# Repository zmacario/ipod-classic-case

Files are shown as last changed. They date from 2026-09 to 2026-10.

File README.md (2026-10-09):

# iPod Classic case — v2

A reworked three-piece screw-together case for the iPod Classic. The three
parts sandwich the iPod: a face plate with the screen and click-wheel
openings, a thick middle frame that holds the device, and a plain rear plate.

Everything is generated from [`generate_case.py`](generate_case.py), so the
design is parametric — edit the numbers at the top and run it again.

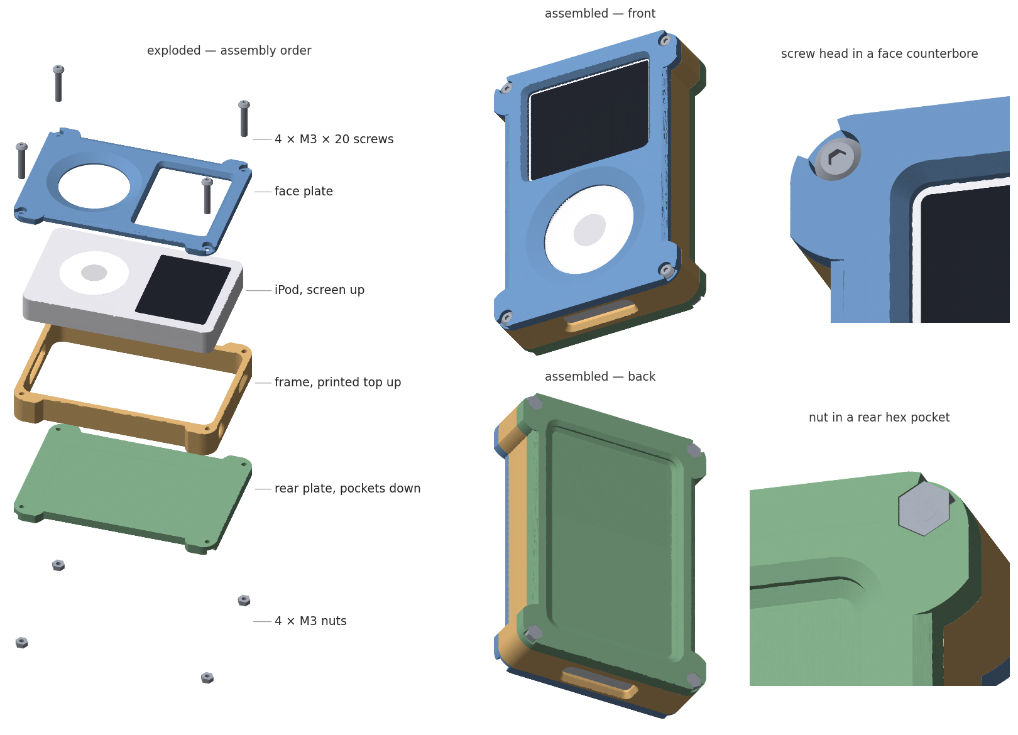
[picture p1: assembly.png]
Assembly of the three v2 parts: exploded order, both assembled sides, and a screw head and a nut in their corner pockets


## What changed from the original

| | original | v2 |
|---|---|---|
| rear plate | 3.50 mm | **5.00 mm** |
| screw length | nothing standard fitted | **M3 × 20, flush** |
| Hold switch | no opening | **14.0 × 5.0 mm window** |
| jack / dock / Hold openings | straight bores | **flared outwards** |
| bottom wall | 5.00 mm | **3.00 mm**, same as the top |
| outer size | 76.80 × 112.20 mm | **76.80 × 110.20 mm** |
| frame/face/rear side walls | solid, 7.30 mm all round | **thin waist, thick only at the screws** |
| face/rear edges | bevel all round, plus a finger-grip scallop on the lower half of each side | **frame's outline, with a bevel along each whole side between the corner pads** |

### Screw length

On the original the path from the counterbore floor to the outer face of the
rear plate measured **18.54 mm**, so an M3 × 20 stood 1.46 mm proud. M3 × 16
could never work: the frame alone is 14 mm, which leaves 2 mm to cross both
plates *and* engage the nut — less than the 2.40 mm thickness of the nut.

The fix was to thicken the rear plate, not the face plate. The rear is a plain
slab, so thickness costs nothing there; thickening the face would sink the
screen and click wheel to the bottom of deeper wells.

| | |
|---|---|
| material under the screw head | 1.000 mm |
| frame | 14.000 mm |
| rear web to the nut | 2.500 mm |
| nut pocket | 2.500 mm |
| **total** | **20.000 mm** |

An M3 × 20 now ends flush with the outer face, with 2.50 mm of thread engaged
in a 2.40 mm nut. Assembled height went from 21.00 to 22.50 mm.

This is what the tested build uses. An M3 × 18 would have allowed a thinner
rear plate, but it could not be found in shops, so the rear stays at 5.00 mm to
suit the M3 × 20.

### Weight reduction

An earlier revision added two extra screws at mid height on the side walls,
for six in total. They never had much clamping to offer — the four corners
already hold the plates flat — and they were the design's weakest point: only
0.97 mm of wall between the hole and the iPod cavity, the thinnest feature in
the whole case.

Back to four corner screws, the entire span between them on each side wall is
free — nothing needs to be routed through it any more. Rather than keep the
full 7.30 mm side wall and hollow it out from inside, the outer silhouette
itself now only carries that thickness where a screw actually needs it —
the same idea as the [iPhone 13 rugged case](https://github.com/zmacario/iphone13-rugged-case)'s
frame, which thickens only around its own screws instead of a uniform wall:

- **Side walls (all three parts)** thin down to 3.00 mm — the same thickness
  already proven by the top/bottom walls — everywhere except within reach of
  a corner screw. There, a local pad restores the original 7.30 mm, blending
  into the thin waist smoothly enough that it needed no explicit fillet.
- **Rear plate** additionally keeps its own pocket across the flat outer
  face, clear of the four screw/nut bosses, leaving 2.50 mm to the inner face
  (the same floor thickness already proven by the hex nut pockets). Neither of
  its edges is sharp: the rim on the outer face and the corner where the wall
  meets the floor both carry the same bevel as the plates' side edges (0.83 mm
  high, 1.93 mm wide), so the wall runs in from the floor, straight for
  0.84 mm, then out to the mouth. At the outer face the mouth comes within
  3.22 mm of the side bevels (5.15 mm before it was bevelled) and 5.52 mm of
  the hex nut pockets.

Face and rear start from the same waisted outline as the frame, so all three
meet flush at every edge; the only thing cut into that outline afterwards is
the side bevel below, on the plates' outer faces. That also meant dropping the
decorative edge chamfer the original design had all round both plates: the
waist isn't convex, so it fought the usual hull-based taper that built that
bevel (see [Regenerating](#regenerating)).

### Side bevel

Each plate bevels the outer-face edge of both sides, along the **whole** side
between the bottom and top corner pads, so no side edge is a sharp corner.
The pads keep their full square edge: the bevel stops exactly where each
pad's arc meets the straight side (y = 16.44 and 93.76 mm) and follows that
arc, so no pad loses material. The frame has no bevel.

| | |
|---|---|
| slope | 2.324 mm in per mm down (same as the click wheel chamfer) |
| down the side | 0.83 mm |
| in across the outer face | 1.93 mm |

That is the profile the original design's finger-grip scallop already left on
the thin waist; `SIDE_BEVEL_SLOPE` and `SIDE_BEVEL_H` in `generate_case.py`
change it.

It replaces that scallop, which was transplanted from the original mesh and
had three problems here: it only existed on the lower half of each side, it
cut a 6.2 × 2.7 mm recess into the bottom pads, and it brought a short stretch
of the original's decorative chamfer with it. Transplanted unclipped, it had
also left both plates overhanging the frame by up to 4.3 mm; `verify_case.py`
now compares full outlines, so neither that nor a bevel reaching into a pad can
pass again.

| part | original | pockets only | thin waist + pads |
|---|---|---|---|
| face | 15.99 cm³ | 15.61 cm³ | 14.06 cm³ |
| frame | 27.43 cm³ | 18.42 cm³ | 16.19 cm³ |
| rear | 41.39 cm³ | 28.89 cm³ | 26.18 cm³ |
| **total** | **84.81 cm³** | **62.92 cm³** | **56.43 cm³** |

A third less material than the original design. All three parts are
verified watertight, with the waist's wall measured at exactly 3.00 mm to
the cavity along its whole length and the corner screws keeping their
original margins (1.87 mm to the cavity, 2.02 mm to the outer edge).

### Flared openings

The jack, dock and Hold openings widen from the cavity towards the outer face
with the same slope as the screen window chamfer (0.6403). Each setback is the
largest the surroundings allow while keeping 1.10 mm of material to the frame
edge:

| opening | inner | outer | setback/side |
|---|---|---|---|
| headphone jack | Ø10.00 | Ø11.20 | 0.60 |
| Hold switch | 14.00 × 5.00 | 16.40 × 7.40 | 1.20 |
| dock connector | 28.83 × 7.94 | 31.23 × 10.34 | 1.20 |

The jack gets half the setback of the others because a Ø10 hole in a 14 mm
frame leaves only 1.71 mm of material above it.

### Bottom wall

The original frame had a 5.00 mm bottom wall and a 3.00 mm top wall. Both
are now 3.00 mm. That works because the top corner screws already sat
against a 3.00 mm wall, clearing the cavity by 1.87 mm and the outer corner
by 2.02 mm; the bottom corners now mirror them exactly.

The iPod cavity does not change, so **the whole case is 2.0 mm shorter**, and
all three parts change with it. Everything positioned against the iPod — the
cavity, the screen window, the click wheel, the jack and the Hold window — is
measured from the cavity floor and stays exactly where it was relative to the
device.

The dock flare still fits, with 1.13 mm of straight bore ahead of it. The one
trade-off is the material bridging the dock cutout: it is now 3 mm deep
instead of 5 mm.

## Fit

The cavity is **62.20 × 104.20 × 14.00 mm**. Width and height suit any
full-size iPod (61.8 × 103.5 mm); the 14 mm depth is what picks the model:

- **iPod 5th gen 60/80 GB** — 14.0 mm, exact, no slack
- **iPod Classic 6th gen 160 GB (2007)** — 13.5 mm, 0.5 mm slack (tested)
- **Classic 6th/7th gen 10.5 mm models** — 3.5 mm of slack, the device rattles

The Hold window was first placed from caliper measurements, then **corrected
after test prints of the frame** on a Classic 6th gen 160 GB: 1.0 mm towards
the headphone jack, and later 1.0 mm towards the face plate (centre z=8.29 of
14, away from the rear plate). That unit's switch is what it matches; if yours
does not line up, adjust `HOLD['x']` / `HOLD['z']` and regenerate.

## Hardware

- 4 × M3 × 20 mm button-head screws (ISO 7380: Ø5.7 head, 1.65 mm tall, sits below the
  face in the 2.5 mm deep Ø6.0 counterbore). A socket-cap head (ISO 4762, 3.0 mm tall)
  also fits but stands about 0.5 mm proud.
- 4 × M3 hex nuts (5.5 mm across flats)

### Corner screw pockets

The corner screws sit so close to the rounded corners that the pockets around
them used to leave walls to the outside thinner than an extrusion line: **0.33
mm** at each hex nut pocket in the rear plate, and **0.59 mm** at each
screw-head counterbore in the face plate — right where the nut or head bears
when the screw is tightened. Thickening them would take squarer corners or
screws moved towards the cavity, and both change the frame.

So wherever such a wall would be thinner than **1.30 mm** (`CORNER_WEB_MIN`:
three 0.4 mm lines plus margin), it is cut away down to the pocket's own floor:
each pocket opens to its corner through an entrance that is flat — not a
slope, the same vertical cut from the floor to the outer face — with sides that
meet the outline square on.

| | rear nut pocket | face counterbore |
|---|---|---|
| floor of the entrance | nut seat, 2.5 mm above the inner face | counterbore floor, 1.0 mm above the inner face |
| wall before | 0.33 mm | 0.59 mm |
| walls left | ~1.3 mm | ~1.3 mm |

A nut still cannot turn (4 of the hex's 6 corners stay walled) or slide out (the
entrance's throat, 4.7 mm, is narrower than the nut's 5.5 mm), and still goes
in from above as before. A screw head still bears on the whole counterbore
floor, which the entrance does not touch.

## Printing

| part | thickness | volume |
|---|---|---|
| face | 3.50 mm | 14.06 cm³ |
| frame | 14.00 mm | 16.19 cm³ |
| rear | 5.00 mm | 26.18 cm³ |

About 67 g in PLA if printed solid (was ~101 g before the weight reduction).

- **Both plates:** flat side down on the bed, **no supports**. The counterbores
  and hex pockets (both with their corner entrances) and the rear pocket open
  upwards, and
  every bevel (sides, pocket rim, pocket floor) narrows as it rises, so none of
  them overhangs. The waist's thin sections need no support either — they are
  just a thinner wall, not an enclosed cavity.
- **Frame:** stands on the bed. It needs a 28.8 mm bridge over the dock cutout
  and a 14 mm one over the Hold window. No supports needed on most printers.
- The frame's port positions are not symmetric through the thickness (jack at
  7.29, dock at 7.70, Hold at 8.29 of 14, measured from the rear plate), so the
  STL's z=0 face — the one on the bed — always goes against the rear plate.

## Assembly

1. Put the iPod into the frame with its screen towards the frame's printed top
   (the side that faced up on the printer).
2. Lay the face plate on that side, counterbores outwards, and the rear plate on
   the other, flat side against the frame and pockets outwards.
3. Push the four M3 × 20 screws in through the face plate's counterbores. Hold
   an M3 nut in each hex pocket of the rear plate and drive the screw from the
   face: the hex keeps the nut from turning. Tighten until snug, not hard —
   the plates are PLA. Each screw ends flush with the rear plate's outer face.

## Regenerating

```bash
python3 -m venv .venv && .venv/bin/pip install manifold3d numpy trimesh matplotlib
.venv/bin/python3 generate_case.py            # writes into stl/
.venv/bin/python3 verify_case.py              # checks the result
.venv/bin/python3 fusion/verify_fusion.py     # checks the Fusion script still matches
.venv/bin/python3 assembly.py                 # redraws assembly.png
```

[`verify_case.py`](verify_case.py) rebuilds the three parts in memory and
checks watertightness/topology, the waist's wall thickness, every corner
screw's clearance, the rear pocket and hex floors, the corner entrances of the
nut pockets and counterbores (flat from their floor, walls left >= 1.2 mm, 4 hex
corners still walled), the rear pocket's exact
bevelled shape and the web it leaves to the nuts, that face and rear
match the frame's full outline at the face that seats against it and never
stick out past it (a full-outline comparison, not a bounding box -- the
bounding box missed a 4.3 mm overhang once), that the side bevel runs every
side between the pads at its designed size while the pads stay untouched, and
that the assembled parts touch without interfering. It replaces the one-off scratchpad scripts this project used to
re-derive these checks after every change.

The generator no longer reads anything from `originals/`: everything,
including the side bevel, is built from the parameters. The original STLs stay
there for reference.

All three parts come out watertight, with consistent winding and the expected
topology (genus 6 / 8 / 4 — one handle per through-hole; the rear plate's
lightening pocket is blind, so it adds none).

The waisted outline is not convex, which is why `outer_profile()` builds it
as a 2D union rather than a hull (`Manifold.batch_hull` always returns
something convex, which would fill the waist back in). A few `.simplify()`
calls (`MESH_TOL`) clean up near-duplicate vertices from the waist's arcs,
ahead of the jack/Hold cuts, so those booleans stay manifold. The side
bevel's cutter stops 0.001 mm (`OVERLAP`) short of each pad's arc for the same
reason: ending exactly on it left a non-manifold edge at every junction.

## Fusion model

[`fusion/ipod_case/`](fusion/ipod_case/) holds a script that rebuilds the same
three parts inside Autodesk Fusion as an editable model. In Fusion:
*Utilities → Add-Ins → Scripts and Add-Ins → Scripts → **+** →* point it at the
`fusion/ipod_case` folder and run it.

It builds the same model as the STLs: the thin waist, the side bevels, the rear
pocket with both edges bevelled, the corner entrances at the nut pockets and
counterbores, and the Hold window where the test prints put it. Fusion keeps
arcs and circles exact where the STLs are tessellated; otherwise the two should
not differ, so a change to `generate_case.py` needs the same change there.

The plate and frame thicknesses and the pocket depths are wired to User
Parameters, so *Modify → Change Parameters* rebuilds those features. The
outline, the bevels and the corner entrances are computed from the constants at
the top of the script when it runs: edit those and run it again. Sketch
profiles use explicit coordinates and are not dimension-driven.

Caveat: the script has **not been executed in Fusion** — it only runs there.
[`fusion/verify_fusion.py`](fusion/verify_fusion.py) checks it instead, by
replaying it against a stand-in for the Fusion API that builds each feature's
solid: all three parts match `generate_case.py`'s to within tessellation
(nothing thicker than 0.1 mm apart, same topology). Run it after changing
either script; `--mutate <name>` plants a known defect (no bevels, no corner
entrances, a thicker waist...) to confirm the check still catches it. The
stand-in cannot catch a mistake in how the real API behaves, so the first run
inside Fusion is the real test; if it stops with an error, the message names
the part it was building.

## Licence

The scripts — `generate_case.py`, `verify_case.py`, `assembly.py` and the Fusion
scripts under `fusion/` — are released under the [MIT licence](LICENSE).

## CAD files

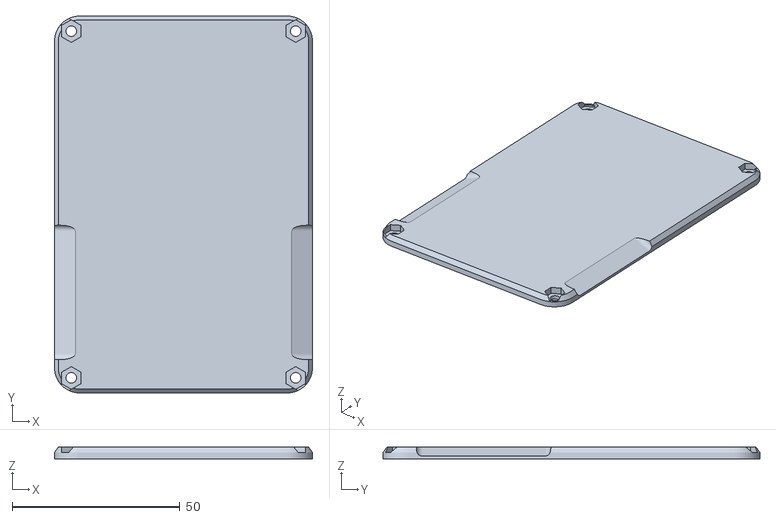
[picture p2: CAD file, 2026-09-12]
originals/simple-ipod-case-rear.stl
76.8 x 112.2 x 3.50

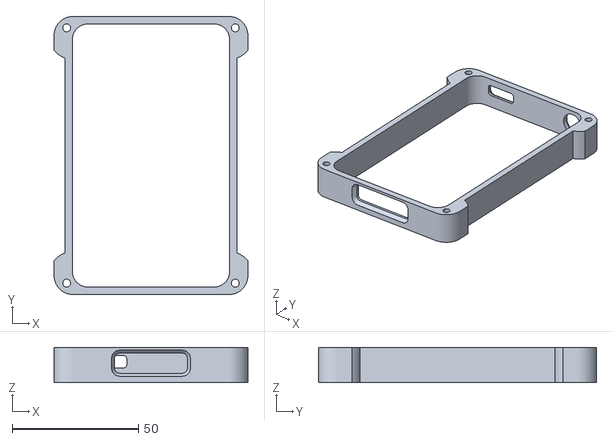
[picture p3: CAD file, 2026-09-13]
stl/simple-ipod-case-thick-frame-v2.stl
76.8 x 110.2 x 14.0

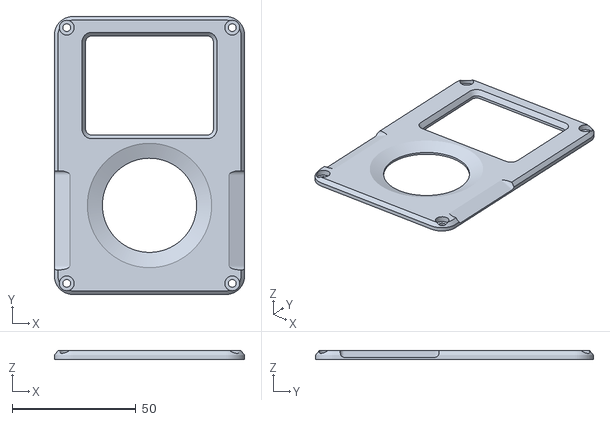
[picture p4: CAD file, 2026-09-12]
originals/simple-ipod-case-face.stl
76.8 x 112.2 x 3.50

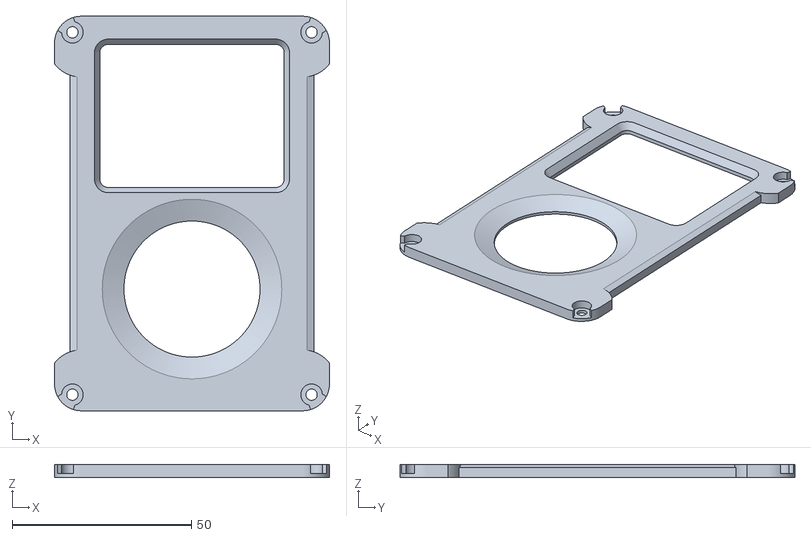
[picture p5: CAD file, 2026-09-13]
stl/simple-ipod-case-face-v2.stl
76.8 x 110.2 x 3.50

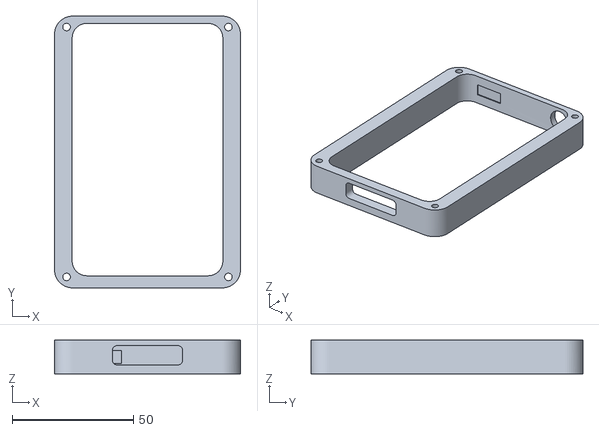
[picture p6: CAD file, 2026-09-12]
originals/simple-ipod-case-thick-frame.stl
76.8 x 112.2 x 14.0

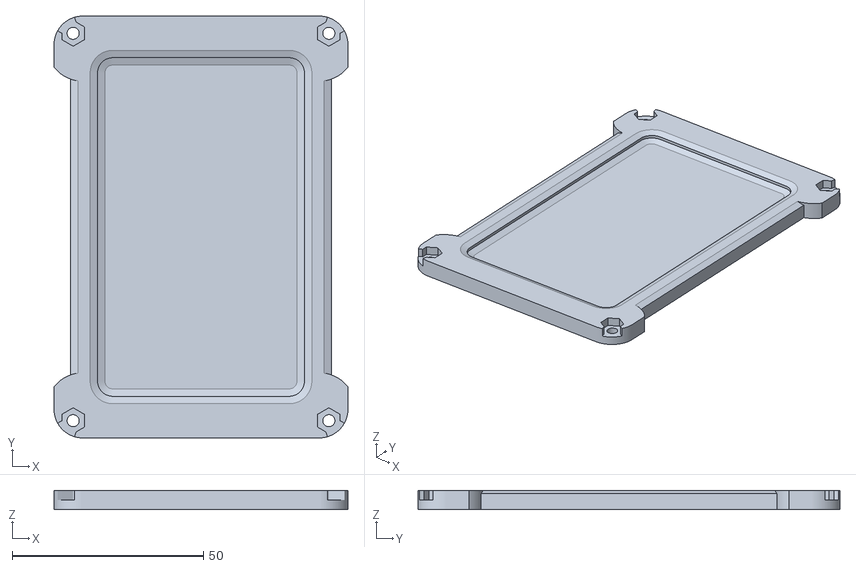
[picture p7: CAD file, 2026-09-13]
stl/simple-ipod-case-rear-v2.stl
76.8 x 110.2 x 5.00

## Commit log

2026-09-12 Rework the three-piece iPod Classic case
    Rebuild all three parts from a parametric generator, reconstructed from
    dimensions measured off the original STLs, with four changes:
    - Six screws instead of four. The two new ones sit mid side wall, 4.75 mm
    from the edge: the 7.299 mm wall only has 1.253 mm to split between the
    counterbore clearing the edge chamfer and the wall left to the cavity.
    - Rear plate 3.50 -> 5.00 mm, which makes the screw path exactly 20.000 mm
    so an M3 x 20 ends flush. M3 x 16 was geometrically impossible: the frame
    alone is 14 mm.
    - A 14.0 x 5.0 mm window for the Hold switch, placed from a measured 31.50 mm
    gap between the switch and the jack hole.
    - Jack, dock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
    [simple-ipod-case-face-v2.stl, simple-ipod-case-face.stl, simple-ipod-case-rear-v2.stl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]
2026-09-13 Move the Hold window 1.0 mm towards the headphone jack
    A test print of the frame showed the Hold window sat 1.0 mm too far from
    the jack. Shift its centre from x=20.84 to x=21.84.
    The window keeps its 14.0 x 5.0 mm size and 1.20 mm flare; the jack hole
    keeps its diameter, flare and position. The bridge between the two
    openings drops from 28.90 to 27.90 mm. Face and rear plates are unchanged
    byte for byte.
    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
    [simple-ipod-case-thick-frame-v2.stl]
2026-09-13 Fix two geometry defects in the generator
    Screw pockets partly refilled by the grip scallop copy. The side scallop
    is transplanted from the original mesh after the part is built, but the
    screws were cut before that, and the transplant boxes (y >= 7.0) reach
    into several screw features. On the rear plate this left the vertex tip
    of the two bottom-corner hex pockets 0.25 mm shallow, and filled a
    0.28 mm wedge into the lower vertex of both mid hex pockets through their
    full depth, which could stop the nut from seating. The face counterbores
    had a negligible 0.04 mm step. Parts now apply the scallop first and cut
    the screws afterwards.
    Tool pieces meeting on a coincident plane. taper() and tape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
    [simple-ipod-case-face-v2.stl, simple-ipod-case-rear-v2.stl, simple-ipod-case-thick-frame-v2.stl]
2026-09-13 Thin the frame's bottom wall to 3.00 mm to match the top
    The bottom wall was 5.00 mm and the top 3.00 mm. The top corner screws
    already sat against a 3.00 mm wall (1.87 mm to the cavity, 2.02 mm to the
    outer corner), so the bottom corners can mirror them with the same
    clearances.
    The iPod cavity is unchanged, so the case is 2.0 mm shorter
    (112.20 -> 110.20 mm) and all three parts change. The cavity, screen
    window, click wheel, jack and Hold window are all measured from the
    cavity floor and keep their position relative to the iPod; a boolean
    diff against the previous parts, aligned on the top edge, shows no
    difference anywhere in the top half. The mid screws move 1.0 mm to stay
    centred and t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
    [simple-ipod-case-face-v2.stl, simple-ipod-case-rear-v2.stl, simple-ipod-case-thick-frame-v2.stl]
2026-09-13 Reduce case weight with lightening pockets, back to 4 screws
    Drop the 2 mid screws, which only ever left 0.97 mm to the cavity for
    little clamping benefit. That frees the whole span between the corner
    screws on each side wall, which is now hollowed into a blind pocket,
    and lets the rear plate's flat outer face take one big pocket clear of
    the nut bosses and grip scallops. Both leave the same floor thickness
    already proven elsewhere (3.00 mm walls, 2.50 mm nut web).
    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
    [simple-ipod-case-face-v2.stl, simple-ipod-case-rear-v2.stl, simple-ipod-case-thick-frame-v2.stl]
2026-09-13 Replace the frame's lightening pocket with a thin waist and screw pads
    Inspired by the iPhone 13 rugged case's frame, which thickens only
    around its own screws instead of carrying a uniform wall: the side
    walls of all three parts now thin down to 3.00 mm almost everywhere,
    with a local pad restoring the original 7.30 mm only within reach of
    a corner screw. Face and rear share the exact same outline as the
    frame so all three still meet flush.
    This replaces the frame's blind side-wall pocket outright (removed)
    and stacks with the rear plate's existing pocket. Total volume drops
    from 62.9 to 57.1 cm3, on top of the previous reduction from 84.8.
    The waisted outline is not convex, which broke t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
    [simple-ipod-case-face-v2.stl, simple-ipod-case-rear-v2.stl, simple-ipod-case-thick-frame-v2.stl]
2026-09-13 Drop the decorative edge chamfer; face and rear follow the frame's outline
    Face and rear no longer taper their outer edge inward near the top --
    both are now a plain extrusion of the same waisted outer_profile() the
    frame uses, so all three parts share an identical silhouette at every
    height, not just at the base.
    This also removes outer_body() and its stepped-slab approximation of
    the chamfer entirely: that workaround only existed to reconcile the
    hull-based taper with the waist's non-convex outline, and with the
    chamfer gone there is nothing left to taper. face()/rear() are now as
    simple as frame() -- a straight prism of outer_profile(), simplified
    once up front, then cut.
    Volumes go up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
    [simple-ipod-case-face-v2.stl, simple-ipod-case-rear-v2.stl]
2026-09-13 Add a standing fit/safety QC pass: verify_case.py
    Consolidates the ad-hoc scratchpad scripts this project kept re-deriving
    after every geometry change into one checked-in script: watertightness,
    topology, the waist's wall thickness, every corner screw's clearance,
    the rear plate's pocket/hex floors, that face/frame/rear share the exact
    same outer silhouette, and that the assembled parts don't interfere.
    Includes absolute safety-floor checks (2.5 mm walls, 2.0 mm floors) that
    don't just read a parameter back against itself -- caught immediately by
    testing against a deliberately thinned WALL_SIDE.
    Also adds a persistent .venv (gitignored) with manifold3d/numpy/trimesh.
2026-09-13 Fix face/rear plates overhanging the frame's waist in the grip band
    The frame's thin waist runs straight through the same y-span as the
    side grip scallop, but only face and rear were getting the grip
    transplant that restores the original mesh's geometry there -- the
    frame just had its normal (thinned) waist across that whole span.
    Result: face and rear's edges sat up to ~3.8 mm outside the frame's,
    clearly visible once assembled. Reported directly by the project
    owner after the previous change.
    The frame gets its own transplant now, from the original thick-frame
    STL (which existed in originals/ but was never wired up -- frame()
    never took a grip argument at all). Applied before the cavity c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
    [simple-ipod-case-thick-frame-v2.stl]
2026-09-13 Restore the frame and clip the plates' grip scallop to its outline
    The previous commit (968b378) got the fix backwards: it changed the
    frame to match the overhanging plates, when the frame was the correct
    reference and the plates were wrong. This reverts that commit -- the
    frame STL is byte-identical to 0e8d686 again -- and fixes the plates.
    The side grip scallop is transplanted from the original meshes, which
    still carry the old full-width side wall, so both plates stuck out up
    to 4.3 mm past the frame's waist along the grip band. The transplant is
    now intersected with the waisted outline: the scallop survives only as
    a bevel inside the contour near each plate's outer face, and nothing
    ove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
    [simple-ipod-case-face-v2.stl, simple-ipod-case-rear-v2.stl, simple-ipod-case-thick-frame-v2.stl]
2026-09-13 Bevel both plates' whole side edges between the corner pads
    The plates' side grip was a scallop transplanted from the original
    meshes: it only existed on the lower half of each side, cut a 6.2 x
    2.7 mm recess into the bottom screw pads, and dragged in a stretch of
    the original's decorative chamfer. Replaced by a parametric bevel
    (SIDE_BEVEL_SLOPE 2.324, SIDE_BEVEL_H 0.83 -- the profile the scallop
    already left on the waist) along every side edge of both plates'
    outer faces, from where the bottom pad's arc meets the straight side
    to where the top one does. The pads' footprint is subtracted from the
    cutter, so the bevel ends following each arc and no pad loses
    material. The frame is untouched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
    [simple-ipod-case-face-v2.stl, simple-ipod-case-rear-v2.stl]
2026-09-13 Bevel the rear pocket's rim and floor edge
    The rear plate's lightening pocket was a straight-walled pit with sharp
    edges. Both edges now carry the plates' side-bevel profile (0.83 mm
    high, 1.93 mm wide, slope 2.324): the rim opens out to the mouth on the
    outer face, and the concave corner at the floor is filled in, so the
    wall runs in from the floor, straight for 0.84 mm, then out. The floor
    stays at REAR_POCKET_KEEP (2.50 mm) everywhere; volume is unchanged
    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
    [simple-ipod-case-rear-v2.stl]
2026-09-13 Open each rear nut pocket to its corner instead of a 0.33 mm wall
    The corner screws sit so close to the rounded corners that every hex
    nut pocket in the rear plate left a 0.33 mm wall to the outside, where
    the nut bears when tightened. Thickening it needs squarer corners or
    screws moved towards the cavity, both frame changes the owner declined.
    nut_pocket() now adds a flat entrance to each hex: the wedge between two
    rays from the corner arc's centre, placed where the radial wall reaches
    NUT_WEB_MIN (1.30 mm), cut from the nut seat straight up through the
    outer face -- no slope, as requested. Its sides meet the outline square
    on; remaining walls are ~1.3 mm; 4 of the hex's 6 corners stay wal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
    [simple-ipod-case-rear-v2.stl]
2026-09-13 Open each face counterbore to its corner instead of a 0.59 mm wall
    The face plate's screw-head counterbores left a 0.59 mm wall to the
    rounded corner. Same fix as the rear nut pockets: wherever that wall
    would be under 1.30 mm it is cut away as a flat entrance from the
    counterbore floor (z = 1.0) up through the outer face. Remaining walls
    are 1.31 mm; the head still bears on the whole counterbore floor, which
    the entrance does not touch.
    The wedge logic moved from nut_pocket() into corner_entrance(pts, x, y),
    used by nut_pocket() and the new counterbore(); NUT_WEB_MIN is now
    CORNER_WEB_MIN. The rear STL is byte-identical after the refactor; only
    the face changed.
    verify_case.py: the nut en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
    [simple-ipod-case-face-v2.stl]
2026-09-13 Move the Hold window 1.0 mm towards the face plate
    A test print of the frame showed the window centred 1.0 mm too close to the
    rear plate. Its centre goes from z=7.29 to 8.29 of 14; the flared mouth now
    leaves 2.04 mm to the face-side edge (was 3.04). Face and rear are unchanged.
    [simple-ipod-case-thick-frame-v2.stl]
2026-09-13 Bring the Fusion script in line with the STLs
    The Fusion script now builds the same parts as generate_case.py: the thin
    waist with corner pads, the side bevels between the pads, the rear pocket's
    rim and floor bevels, and the flat corner entrances at the nut pockets and
    counterbores. The old grip scallop and frame side pocket are gone.
    Also fixes a bug it had all along: the screen window's straight cut started
    0.19 mm above the face's inner surface, leaving a skin across the window.
    Checked by replaying the script against a stand-in for the Fusion API that
    builds each feature's solid: all three parts match generate_case.py's to
    within tessellation. Not yet run inside Fusion itself.
2026-09-13 Add a check that the Fusion script builds the same parts as the STLs
    fusion/verify_fusion.py replays the Fusion script against a stand-in for the
    Fusion API that turns each sketch and feature into a solid, and compares the
    three parts with generate_case.py's: same genus, nothing thicker than 0.1 mm
    apart. --mutate plants a known defect to confirm the check still bites.
2026-09-13 Add an assembly figure to the README
    assembly.py renders assembly.png from generate_case.py's parts, with simple
    stand-ins for the iPod, the M3 x 20 screws and the nuts: an exploded view in
    assembly order, the assembled case from the front and the back, and close-ups
    of a screw head and a nut in their corner pockets. The README gains the
    figure and a short Assembly section.
